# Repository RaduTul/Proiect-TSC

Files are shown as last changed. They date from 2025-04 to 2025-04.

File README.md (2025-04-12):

# Proiect-TSC 
Tulumb Radu Cristian 332CB
e-book reader

Procesul de dezvoltare
In prima parte a proiectului cand am realizat schematicul m-am folosit de descrierea pieselor din pdf-ul de pe OCW pentru a denumi, aranja si a da valori componentelor. Am schimbat de fiecare data layerul cand ba puneam nets ba symbols ba lines. M-am folosit de toolurile necesare pentru a schimba numele si valorile pieselor apoi am dat switch in PCB.
In PCB am tinut cont de masuratorile de pe OCW si de pozitia componentelor. Ca sa ma asigur ca dimensiunea placutei este corecta am modificat gridul PCB-ului in 1 mm cu 1 mm pentru a determina daca este dimensiunea corecta. Rutarea a fost mai complicata, dar am reusit sa o fac pe layerul de top si bottom. Mai aveam doua erori hole carora le-am dat approve. Pentru a continua am dat switch in PCB3D.
Am cautat piesele individual folosind design manager si sintaxa (ObjectType = Device) AND (Name = "piesa respectiva") pentru a cauta piesa pentru care urma sa fac un model 3D. Modelele 3D au fost luate de pe SnapMagic, Mouser, SnapEDA si componentsearchengine unde am gasit modelele 3D pentru fiecare piesa in parte. Am creat un fisier special cu toate modelele 3D necesare, le-am rotit si ajustat pentru a se incadra in linia punctata verde si intre cele doua puncte verzi si i-am dat replace package apoi am salvat, am dat in PCB update apoi cand dadeam switch to PCB3D imi punea piesa pe placuta. Pentru TP-uri am desenat un cerc.
Pentru generarea fisierelor Gerber am folosit optiunea de Fabrication Outputs din meniul MANUFACTURE din Fusion 360. Am selectat toate straturile necesare (Top Copper, Bottom Copper, Top Mask, Bottom Mask, Top Paste, Bottom Paste, Top Silkscreen, Bottom Silkscreen si Edge Cuts) si am generat fisierele in formatul cerut.
Am generat fisierul BOM (Bill of Materials) utilizand functionalitatea din meniul MANAGE, selectand toate componentele folosite in proiect si exportand in formatul CSV, apoi l-am salvat in directorul Manufacturing.
Fisierul Pick and Place (CPL) a fost generat din meniul MANUFACTURE, sectiunea Assembly, selectand optiunile pentru coordonatele componentelor si formatand corespunzator pentru productie.
Probleme la implementare
Aprobarea erorilor
La rutarea PCB-ului a fost nevoie sa aprob 2 erori de "hole" cauzate de componentele SMD.
Lipsa model 3D
Pentru TP-uri nu am gasit un model 3D, asa ca am facut un cerc pe care l-am ridicat putin.

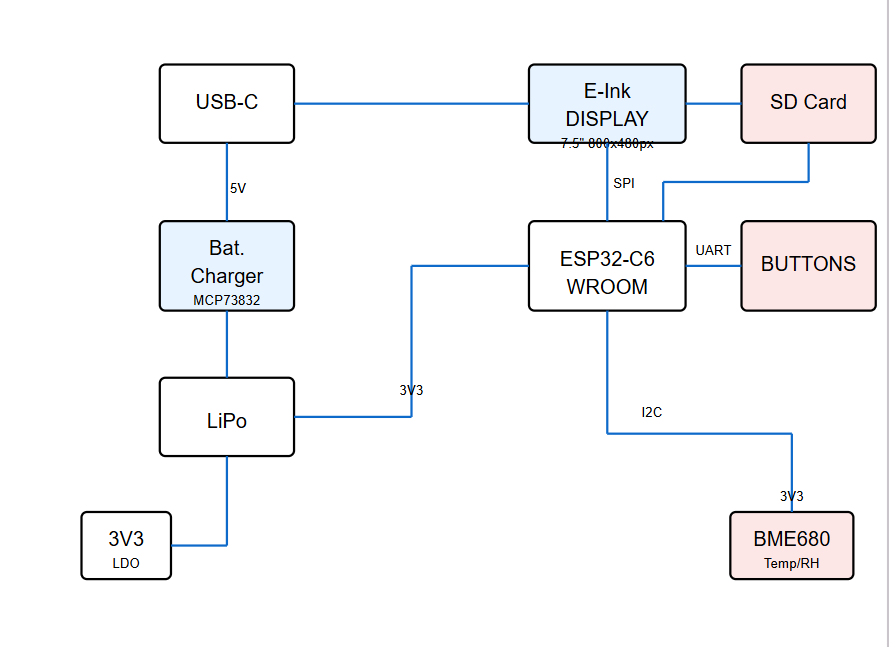
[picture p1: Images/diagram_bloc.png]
Diagrama Bloc OpenBook


[(BOM)](Manufacturing/BOM_proiect2025%20v19.csv)

## Functionalitatile Hardware
Acest e-book reader foloseste un microcontroller ESP32-C6 WROOM care controleaza un display e-ink de 7.5" cu rezolutie 800x480px. Dispozitivul include urmatoarele componente principale:
Componente Hardware Utilizate

ESP32-C6: Microcontroller principal pentru procesarea datelor si conectivitate.
E-Paper Display 7.5": Display cu consum redus de energie, conectat prin SPI.
Conectori pentru SD Card: Permite stocarea suplimentara a cartilor electronice.
Memorie NOR Flash W25Q512: Stocare suplimentara pentru fisiere tip e-book.
Baterie Li-Po: Sursa principala de alimentare a dispozitivului.
Conector USB-C: Permite incarcarea si transferul de date.
Modul RTC DS3231SN: Functionalitate de ceas in timp real.
Senzor BME680: Monitorizeaza temperatura si umiditate prin interfata I2C.
MAX17048G: Circuit de management pentru baterie.

## Interfete Principale

SPI: Utilizata pentru E-Paper display si memoria Flash.
I2C: Conecteaza senzorul BME680 si modulul RTC.
GPIO: Utilizati pentru butoane si alte componente periferice.

## Pini Utilizati - ESP32-C6

GPIO6 (IO6): SCK pentru interfata SPI (inlocuieste GPIO3/GPIO18/GPIO19 din listarea initiala).
GPIO2 (IO2): MISO pentru interfata SPI.
GPIO7 (IO7): MOSI pentru interfata SPI (inlocuieste GPIO1 din listarea initiala).
GPIO11 (IO11): Chip Select pentru memoria Flash (inlocuieste GPIO5 din listarea initiala).
GPIO3 (IO3): Reset pentru E-Paper (inlocuieste GPIO4 din listarea initiala).
GPIO4 (IO4): Chip Select pentru cardul SD (inlocuieste GPIO10 din listarea initiala).
GPIO22 (IO22): SCL pentru interfata I2C.
GPIO21 (IO21): SDA pentru interfata I2C.
GPIO16 (IO16): TX pentru comunicatie seriala.
GPIO17 (IO17): RX pentru comunicatie seriala.
GPIO20 (IO20): Conectat la butonul BOOT.
GPIO21 (IO21): Conectat la butonul RESET (posibil duplicat cu SDA, necesita verificare in schematic).
GPIO22 (IO22): Conectat la butonul CHANGE (posibil duplicat cu SCL, necesita verificare in schematic).

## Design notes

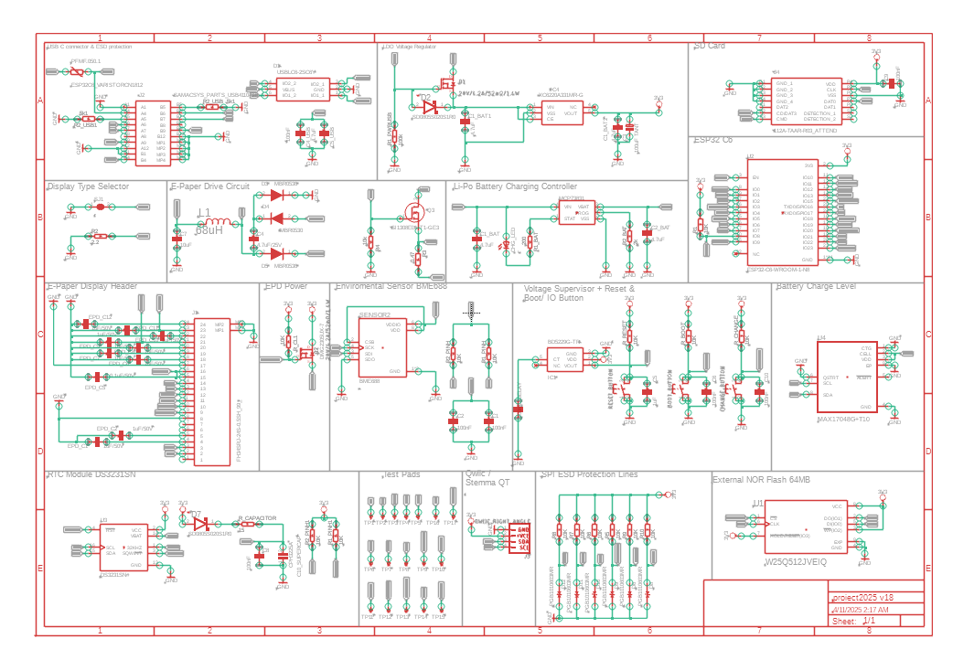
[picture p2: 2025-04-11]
Images/schematicdupareview.PNG

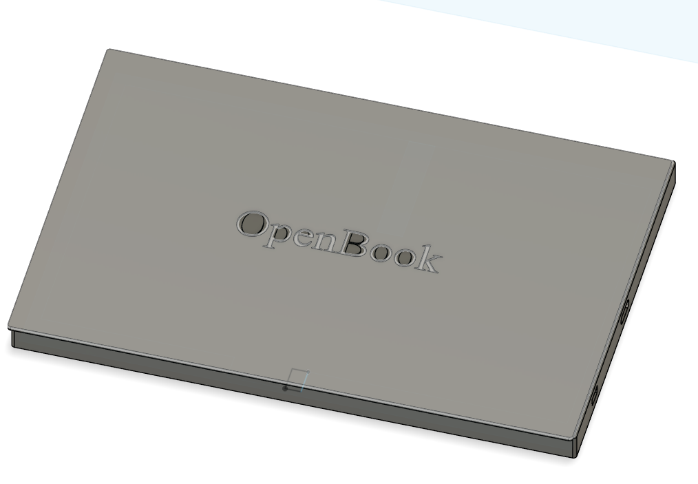
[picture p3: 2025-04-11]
Images/carcasainchisa.PNG

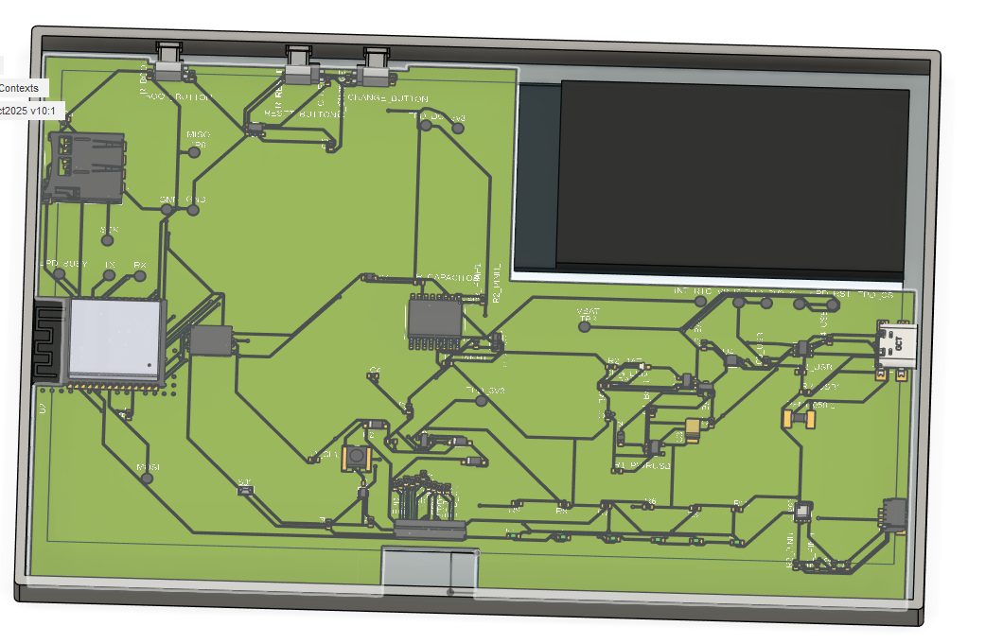
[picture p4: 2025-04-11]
Images/3docbdupareview.PNG

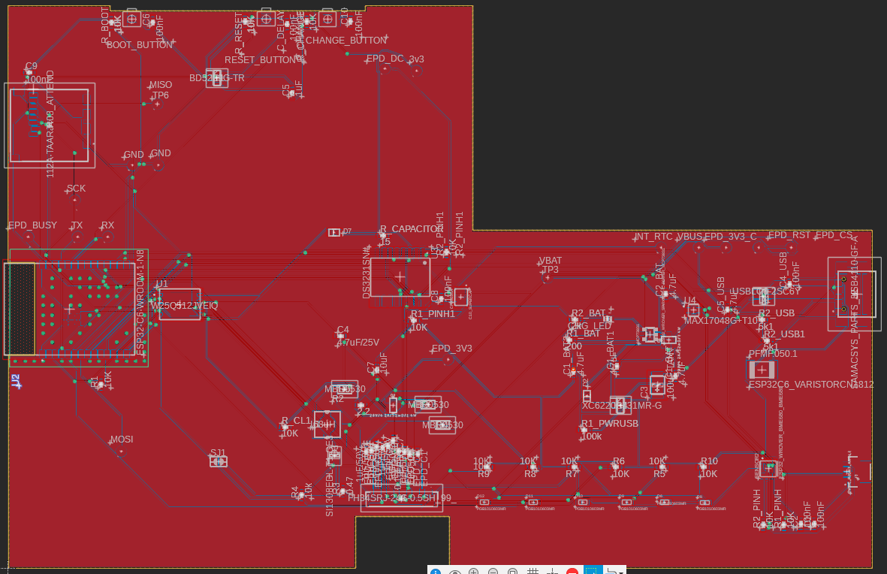
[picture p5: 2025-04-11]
Images/pcbafterreview.PNG

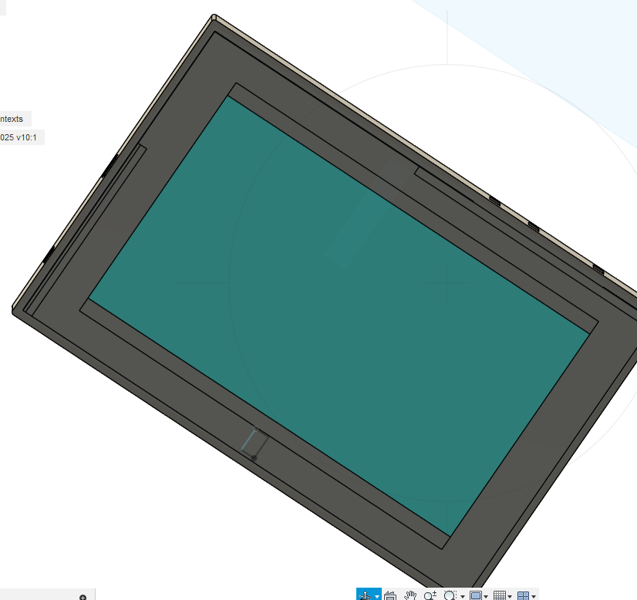
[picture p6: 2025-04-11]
Images/carcasa displau.PNG

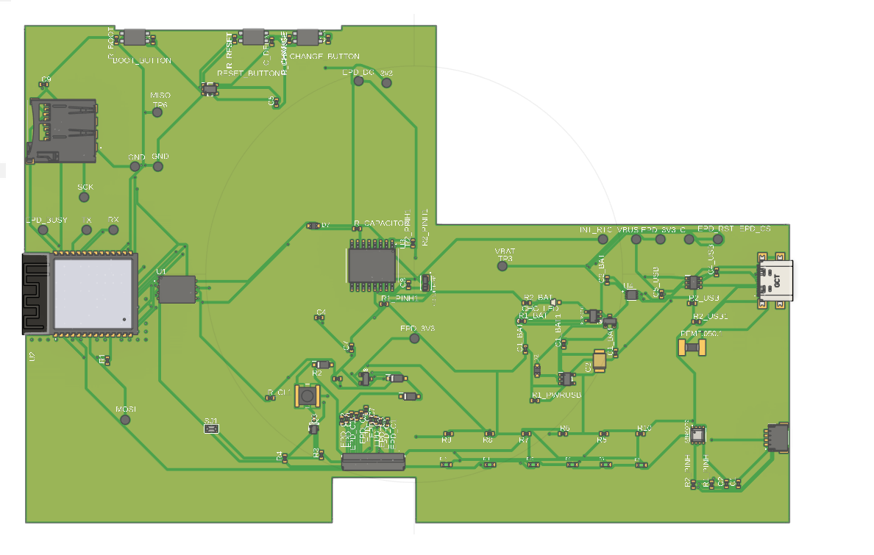
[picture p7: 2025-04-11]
Images/pcb3ddupareview.PNG

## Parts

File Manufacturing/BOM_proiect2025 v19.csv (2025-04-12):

Qty | Value | Device | Package | Parts | Description | ARROW_PART_NUMBER | ARROW_PRICE-STOCK | AVAILABILITY | CENTROID_NOT_SPECIFIED | CHECK_PRICES | COPYRIGHT | DATASHEET | DESCRIPTION | DIGIKEY_DESCRIPTION | DIGIKEY_PART_NUMBER | HEIGHT | LEAD_FREE | MANUFACTURER_NAME | MANUFACTURER_PART_NUMBER | MF | MFR_NAME | MOUSER_PART_NUMBER | MOUSER_PRICE-STOCK | MOUSER_TESTING_PART_NUMBER | MOUSER_TESTING_PRICE-STOCK | MP | MPN | PACKAGE | POPULARITY | PREFIX | PRICE | PROD_ID | PURCHASE-URL | ROHS | SNAPEDA_LINK | SPICEMODEL | SPICEPREFIX | TEMPERATURE_RANGE_HIGH | TEMPERATURE_RANGE_LOW | TP_SIGNAL_NAME | VALUE
1 |  | ADAFRUIT_LEDCHIP-LED0603 | ADAFRUIT_CHIP-LED0603 | CHG_LED | LED
2 |  | ESP32_WROVER_EAGLE-LTSPICE_RR0402 | ESP32_WROVER_EAGLE-LTSPICE_R0402 | R1, R2 | RESISTOR, European symbol |  |  |  |  |  |  |  |  |  |  |  |  |  |  |  |  |  |  |  |  |  |  |  |  |  |  |  |  |  |  | NONE | R
1 |  | SJ | SJ | SJ1 | SMD solder JUMPER |  |  |  |  |  |  |  |  |  |  |  |  |  |  |  |  |  |  |  |  |  |  |  | 3
1 | 0.1uF/50V | EAGLE-LTSPICE_CC0402 | EAGLE-LTSPICE_C0402 | EPD_C5 | CAPACITOR, European symbol |  |  |  |  |  |  |  |  |  |  |  |  |  |  |  |  |  |  |  |  |  |  |  |  |  |  |  |  |  |  | NONE | C
1 | 0.47 | ESP32_WROVER_EAGLE-LTSPICE_RR0402 | ESP32_WROVER_EAGLE-LTSPICE_R0402 | R3 | RESISTOR, European symbol |  |  |  |  |  |  |  |  |  |  |  |  |  |  |  |  |  |  |  |  |  |  |  |  |  |  |  |  |  |  | NONE | R
1 | 100k | ESP32_WROVER_EAGLE-LTSPICE_RR0402 | ESP32_WROVER_EAGLE-LTSPICE_R0402 | R1_PWRUSB | RESISTOR, European symbol |  |  |  |  |  |  |  |  |  |  |  |  |  |  |  |  |  |  |  |  |  |  |  |  |  |  |  |  |  |  | NONE | R
8 | 100nF | EAGLE-LTSPICE_CC0402 | EAGLE-LTSPICE_C0402 | C1, C2, C4_USB, C6, C8, C9, C10, C_DELAY | CAPACITOR, European symbol |  |  |  |  |  |  |  |  |  |  |  |  |  |  |  |  |  |  |  |  |  |  |  |  |  |  |  |  |  |  | NONE | C
1 | 100uF TANT | RCL_CPOL-EUCT3528 | RCL_CT3528 | C3 | POLARIZED CAPACITOR, European symbol |  |  |  |  |  |  |  |  |  |  |  |  |  |  |  |  |  |  |  |  |  |  |  | 0 |  |  |  |  |  |  |  | C
14 | 10K | ESP32_WROVER_EAGLE-LTSPICE_RR0402 | ESP32_WROVER_EAGLE-LTSPICE_R0402 | R1_PINH, R1_PINH1, R2_PINH, R2_PINH1, R5, R6, R7, R8, R9, R10, R_BOOT, R_CHANGE, R_CL1, R_RESET | RESISTOR, European symbol |  |  |  |  |  |  |  |  |  |  |  |  |  |  |  |  |  |  |  |  |  |  |  |  |  |  |  |  |  |  | NONE | R
1 | 10k | ESP32_WROVER_EAGLE-LTSPICE_RR0402 | ESP32_WROVER_EAGLE-LTSPICE_R0402 | R4 | RESISTOR, European symbol |  |  |  |  |  |  |  |  |  |  |  |  |  |  |  |  |  |  |  |  |  |  |  |  |  |  |  |  |  |  | NONE | R
1 | 10uF | EAGLE-LTSPICE_CC0402 | EAGLE-LTSPICE_C0402 | C7 | CAPACITOR, European symbol |  |  |  |  |  |  |  |  |  |  |  |  |  |  |  |  |  |  |  |  |  |  |  |  |  |  |  |  |  |  | NONE | C
1 | 112A-TAAR-R03_ATTEND | 112A-TAAR-R03_ATTEND | 112ATAARR03ATTEND | J4 | Micro SD Card Socket, Push-Push Type, Top Mount, SMT, H=1.83mm, 10u |  |  |  |  |  |  |  | Micro SD Card Socket | Push-Push Type | Top Mount | SMT | H=1.83mm | 10u |  |  | 1.9mm |  | ATTEND | 112A-TAAR-R03 ATTEND
1 | 15 | ESP32_WROVER_EAGLE-LTSPICE_RR0402 | ESP32_WROVER_EAGLE-LTSPICE_R0402 | R_CAPACITOR | RESISTOR, European symbol |  |  |  |  |  |  |  |  |  |  |  |  |  |  |  |  |  |  |  |  |  |  |  |  |  |  |  |  |  |  | NONE | R
1 | 1uF | EAGLE-LTSPICE_CC0402 | EAGLE-LTSPICE_C0402 | C5 | CAPACITOR, European symbol |  |  |  |  |  |  |  |  |  |  |  |  |  |  |  |  |  |  |  |  |  |  |  |  |  |  |  |  |  |  | NONE | C
9 | 1uF/50V | EAGLE-LTSPICE_CC0402 | EAGLE-LTSPICE_C0402 | EPD_C1, EPD_C2, EPD_C6, EPD_C7, EPD_C8, EPD_C9, EPD_C10, EPD_C11, EPD_C12 | CAPACITOR, European symbol |  |  |  |  |  |  |  |  |  |  |  |  |  |  |  |  |  |  |  |  |  |  |  |  |  |  |  |  |  |  | NONE | C
1 | 200 | ESP32_WROVER_EAGLE-LTSPICE_RR0402 | ESP32_WROVER_EAGLE-LTSPICE_R0402 | R1_BAT | RESISTOR, European symbol |  |  |  |  |  |  |  |  |  |  |  |  |  |  |  |  |  |  |  |  |  |  |  |  |  |  |  |  |  |  | NONE | R
2 | 20V/4.2A/52mO/1.4W | ESP32_WROVER_SPARKFUN-DISCRETESEMI_MOSFET_PCH-DMG2305UX-7 | ESP32_WROVER_SPARKFUN-DISCRETESEMI_SOT23-3 | Q1, Q2 | P-channel MOSFETs |  |  |  |  |  |  |  |  |  |  |  |  |  |  |  |  |  |  |  |  |  |  |  |  |  |  | TRAN-14388 |  |  |  |  |  |  |  |  | 20V/4.2A/52mO/1.4W
1 | 2k | ESP32_WROVER_EAGLE-LTSPICE_RR0402 | ESP32_WROVER_EAGLE-LTSPICE_R0402 | R2_BAT | RESISTOR, European symbol |  |  |  |  |  |  |  |  |  |  |  |  |  |  |  |  |  |  |  |  |  |  |  |  |  |  |  |  |  |  | NONE | R
5 | 4.7uF | EAGLE-LTSPICE_CC0402 | EAGLE-LTSPICE_C0402 | C1_BAT, C1_BAT1, C1_BAT2, C2_BAT, C5_USB | CAPACITOR, European symbol |  |  |  |  |  |  |  |  |  |  |  |  |  |  |  |  |  |  |  |  |  |  |  |  |  |  |  |  |  |  | NONE | C
1 | 4.7uF/25V | EAGLE-LTSPICE_CC0402 | EAGLE-LTSPICE_C0402 | C4 | CAPACITOR, European symbol |  |  |  |  |  |  |  |  |  |  |  |  |  |  |  |  |  |  |  |  |  |  |  |  |  |  |  |  |  |  | NONE | C
2 | 5k1 | ESP32_WROVER_EAGLE-LTSPICE_RR0402 | ESP32_WROVER_EAGLE-LTSPICE_R0402 | R2_USB, R2_USB1 | RESISTOR, European symbol |  |  |  |  |  |  |  |  |  |  |  |  |  |  |  |  |  |  |  |  |  |  |  |  |  |  |  |  |  |  | NONE | R
1 | 68uH | 744043680IND_4828-WE-TPC_WRE | IND_4828-WE-TPC_WRE | L1 |  |  |  |  |  |  | Copyright (C) 2024 Ultra Librarian. All rights reserved. |  |  |  |  |  |  |  | 744043680 |  | Wurth Electronics
1 | BD5229G-TR | BD5229G-TR | SOT95P280X125-5N | IC1 | Voltage Detector with Adjustable Delay Time: CMOS processes are utilized to develop high precision, low current consumption CMOS reset ICs that allow arbitrary setting of the delay time. The extensive lineup includes both Nch Open Drain and CMOS output types in a wide range of detection voltages (from 2.3V to 6.0V, in 0.1V steps), enabling selection of the ideal solution based on customer requirements. In addition, the entire series is of course both lead-free and RoHS-compliant. |  |  |  |  |  |  |  | Voltage Detector with Adjustable Delay Time: CMOS processes are utilized to develop high precision | low current consumption CMOS reset ICs that allow arbitrary setting of the delay time. The extensive lineup includes both Nch Open Drain and CMOS output types in a wide range of detection voltages (from 2.3V to 6.0V | in 0.1V steps) | enabling selection of the ideal solution based on customer requirements. In addition | the entire series is of course both lead-free and RoHS-compliant. |  |  | 1.25mm |  | ROHM Semiconductor | BD5229G-TR |  |  | 755-BD5229G-TR | https://www.mouser.co.uk/ProductDetail/ROHM-Semiconductor/BD5229G-TR?qs=4kLU8WoGk0vvnhrrYwdszw%3D%3D
3 | BUTTON_CUSYOMV1 | BUTTON_CUSYOMV1 | MYBUTTON | BOOT_BUTTON, CHANGE_BUTTON, RESET_BUTTON |  |  |  |  |  |  |  |  |  |  |  |  |  |  |  |  |  |  |  |  |  |  | https://www.mouser.co.il/ProductDetail/SparkFun/COM-09190?qs=WyAARYrbSnYmfgv9mXV0oQ%3D%3D
1 | CPH3225A | CPH3225A | CAPCP3225X100N | C10_SUPERCAP | Cap 0.011F 3.3V 1210 Flat Check availability |  |  | Not in stock |  | https://www.snapeda.com/parts/CPH3225A/Seiko+Instruments/view-part/?ref=eda |  |  | 11 mF (EDLC) Supercapacitor 3.3 V 1210 (3225 Metric) - - |  |  |  |  |  |  | Seiko Instruments |  |  |  |  |  | CPH3225A |  | 1210 Seiko |  |  | None |  | https://www.snapeda.com/api/url_track_click_mouser/?unipart_id=562593&manufacturer=Seiko Instruments&part_name=CPH3225A&search_term=None |  | https://www.snapeda.com/parts/CPH3225A/Seiko+Instruments/view-part/?ref=snap
1 | DS3231SN# | DS3231SN# | SOIC127P1032X265-16N | U3 | Real Time Clock Serial 16-Pin SOIC W T/R Check availability |  |  | In Stock |  | https://www.snapeda.com/parts/DS3231SN%23/Analog+Devices/view-part/?ref=eda |  |  | Extremely Accurate I²C-Integrated RTC/TCXO/Crystal |  |  |  |  |  |  | Analog Devices |  |  |  |  |  | DS3231SN# |  | SOIC-16 Maxim |  |  | None |  | https://www.snapeda.com/api/url_track_click_mouser/?unipart_id=99048&manufacturer=Analog Devices&part_name=DS3231SN#&search_term=None |  | https://www.snapeda.com/parts/DS3231SN%23/Analog+Devices/view-part/?ref=snap
1 | ESP32-C6-WROOM-1-N8 | ESP32-C6-WROOM-1-N8 | XCVR_ESP32-C6-WROOM-1-N8 | U2 | Check availability |  |  | In Stock |  | https://www.snapeda.com/parts/ESP32-C6-WROOM-1-N8/Espressif+Systems/view-part/?ref=eda |  |  | Multiprotocol Modules ESP32-C6 module | Wi-Fi 6 in 2.4 GHz band | Bluetooth 5 | Zigbee 3.0 and Thread. ESP34-WROOM Compatible - ENGINEERING SAMPLE |  |  |  |  |  |  | Espressif Systems |  |  |  |  |  | ESP32-C6-WROOM-1-N8 |  | None |  |  | None |  |  |  | https://www.snapeda.com/parts/ESP32-C6-WROOM-1-N8/Espressif+Systems/view-part/?ref=snap
1 | ESP32C6_VARISTORCN1812 | ESP32C6_VARISTORCN1812 | ESP32C6_VARISTOR_CT/CN1812 | PFMF.050.1 | VARISTOR |  |  |  |  |  |  |  |  |  |  |  |  |  |  |  |  |  |  |  |  |  | https://eu.mouser.com/ProductDetail/Espressif-Systems/ESP32-C6?qs=Imq1NPwxi75noDtUpuVuWw%3D%3D |  | 0
2 | ESP32_WROVER_AVX---SD0805S020S1R0_AVX_SD0805S020S1R0_0_0AVX_SD0805S020S1R0_0_0 | ESP32_WROVER_AVX---SD0805S020S1R0_AVX_SD0805S020S1R0_0_0AVX_SD0805S020S1R0_0_0 | ESP32_WROVER_AVX---SD0805S020S1R0_AVX_SD0805S020S1R0_0 | D2, D7 | Schottky Barrier Rectifier Diode |  |  |  | No |  |  | http://datasheets.avx.com/schottky.pdf |  | DIODE SCHOTTKY 20V 1A 0805 | 478-7800-1-ND |  | yes |  |  | AVX |  | 581-SD0805S020S1R0 |  |  |  |  | https://eu.mouser.com/ProductDetail/Espressif-Systems/ESP32-WROVER-IE-N4R8?qs=Li%252BoUPsLEntmub0i0FT64w%3D%3D | 0805 (2012 metric) |  | D |  |  |  | yes |  |  |  | +125°C | -55°C
1 | ESP32_WROVER_BME680_BME680 | ESP32_WROVER_BME680_BME680 | ESP32_WROVER_BME680_PSON80P300X300X100-8N | SENSOR2 | Integrated Environmental Unit |  |  | Unavailable |  |  |  |  | Integrated Environmental Unit |  |  |  |  |  |  | Bosch Sensortec |  |  |  |  |  | BME680 | https://ro.mouser.com/ProductDetail/Bosch-Sensortec/BME680?qs=v271MhAjFHjo0yA%2FC4OnDQ%3D%3D | LGA-8 Bosch Tools |  |  | None
1 | ESP32_WROVER_SPARKFUN-IC-POWER_MCP73831 | ESP32_WROVER_SPARKFUN-IC-POWER_MCP73831 | ESP32_WROVER_SPARKFUN-IC-POWER_SOT23-5 | MCP73831 | MCP73831T Li-Ion, Li-Pol Controller |  |  |  |  |  |  |  |  |  |  |  |  |  |  |  |  |  |  |  |  |  | https://eu.mouser.com/ProductDetail/Microchip-Technology/MCP73831T-2ACI-OT?qs=yUQqVecv4qvbBQBGbHx0Mw%3D%3D |  |  |  |  | IC-09995
1 | FH34SRJ-24S-0.5SH_99_ | FH34SRJ-24S-0.5SH_99_ | FH34SRJ24S05SH99 | J1 | (0.50mm) Surface Mount, Right Angle |  |  |  |  |  |  |  | 24 Position FFC | FPC Connector Contacts | (0.50mm) Surface Mount | Right Angle |  |  | 1.1mm |  | Hirose | FH34SRJ-24S-0.5SH(99) |  |  | 798-FH34SRJ24S05SH99 | https://www.mouser.co.uk/ProductDetail/Hirose-Connector/FH34SRJ-24S-0.5SH99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
1 | MAX17048G+T10 | MAX17048G+T10 | SON50P200X200X80-9N | U4 | Check availability |  |  | In Stock |  | https://www.snapeda.com/parts/MAX17048G+T10/Analog+Devices/view-part/?ref=eda |  |  | 3µA 1-Cell/2-Cell Fuel Gauge with ModelGauge |  |  |  |  |  |  | Analog Devices |  |  |  |  |  | MAX17048G+T10 |  | TDFN-8 Maxim |  |  | None |  | https://www.snapeda.com/api/url_track_click_mouser/?unipart_id=329239&manufacturer=Analog Devices&part_name=MAX17048G+T10&search_term=None |  | https://www.snapeda.com/parts/MAX17048G+T10/Analog+Devices/view-part/?ref=snap
3 | MBR0530 | MBR0530 | SOD3716X135N | D3, D4, D5 | ON SEMICONDUCTOR - MBR0530 - DIODE, SCHOTTKY, 0.5A, 30V, SOD-123 |  |  | In Stock |  | https://www.snapeda.com/parts/MBR0530/Onsemi/view-part/?ref=eda |  |  | Diode Schottky 30 V 500mA Surface Mount SOD-123 |  |  |  |  |  |  | ON Semiconductor |  |  |  |  |  | MBR0530 |  | SOD-123-2 ON Semiconductor |  |  | None |  | https://www.snapeda.com/api/url_track_click_mouser/?unipart_id=179458&manufacturer=ON Semiconductor&part_name=MBR0530&search_term=None |  | https://www.snapeda.com/parts/MBR0530/Onsemi/view-part/?ref=snap
6 | PGB1010603MR | PGB1010603MR | DIOC1608X36N | D6, D8, D9, D10, D11, D12 | Check availability |  |  | In Stock |  | https://www.snapeda.com/parts/PGB1010603MR/Littelfuse/view-part/?ref=eda |  |  | 150V (Typ) Clamp - Ipp Tvs Diode Surface Mount 0603 (1608 Metric) |  |  |  |  |  |  | Littelfuse Inc. |  |  |  |  |  | PGB1010603MR |  | 0603 Littelfuse Inc. |  |  | None |  | https://www.snapeda.com/api/url_track_click_mouser/?unipart_id=5659453&manufacturer=Littelfuse Inc.&part_name=PGB1010603MR&search_term=None |  | https://www.snapeda.com/parts/PGB1010603MR/Littelfuse/view-part/?ref=snap
1 | QWIIC_RIGHT_ANGLE | QWIIC_CONNECTORJS-1MM | JST04_1MM_RA | J3 | SparkFun I2C Standard Qwiic Connector |  |  |  |  |  |  |  |  |  |  |  |  |  |  |  |  |  |  |  |  |  | https://ro.mouser.com/new/sparkfun/sparkfun-qwiic-connect-system/ |  |  |  |  | CONN-13694 |  |  |  |  |  |  |  |  | QWIIC_RIGHT_ANGLE
1 | SAMACSYS_PARTS_USB4110-GF-A | SAMACSYS_PARTS_USB4110-GF-A | SAMACSYS_PARTS_USB4110GFA | J2 | CONN USB 2.0 TYPE-C R/A SMT |  |  |  |  |  |  |  | CONN USB 2.0 TYPE-C R/A SMT |  |  | 3.26mm |  | GCT (GLOBAL CONNECTOR TECHNOLOGY) | USB4110-GF-A |  |  | 640-USB4110-GF-A | https://www.mouser.co.uk/ProductDetail/GCT/USB4110-GF-A?qs=KUoIvG%2F9IlYiZvIXQjyJeA%3D%3D
1 | SI1308EDL-T1-GE3 | SI1308EDL-T1-GE3 | SOT65P210X110-3N | Q3 | MOSFET N-Ch 30V 1.5A TrenchFET SC70 Vishay Si1308EDL-T1-GE3 N-channel MOSFET Transistor, 1.5 A, 30 V, 3-Pin SC-70 |  |  | In Stock |  | https://www.snapeda.com/parts/SI1308EDL-T1-GE3/Vishay+Siliconix/view-part/?ref=eda |  |  | Si1308EDL-T1-GE3 N-channel MOSFET Transistor | 1.5 A | 30 V | 3-Pin SC-70 | Siliconix / Vishay SI1308EDL-T1-GE3 |  |  |  |  |  |  | Vishay Siliconix |  |  |  |  |  | SI1308EDL-T1-GE3 |  | SOT-323 Vishay Semiconductor |  |  | None |  | https://www.snapeda.com/api/url_track_click_mouser/?unipart_id=274603&manufacturer=Vishay Siliconix&part_name=SI1308EDL-T1-GE3&search_term=None |  | https://www.snapeda.com/parts/SI1308EDL-T1-GE3/Vishay+Siliconix/view-part/?ref=snap
17 | TPTP20R | TPTP20R | TP20R | TP1, TP2, TP3, TP4, TP5, TP6, TP7, TP8, TP9, TP10, TP11, TP12, TP13, TP14, TP15, TP16, TP17 | Test pad |  |  |  |  |  |  |  |  |  |  |  |  |  |  |  |  |  |  |  |  |  |  |  | 2
1 | USBLC6-2SC6Y | USBLC6-2SC6Y | SOT95P280X145-6N | D1 | Low Cap. ESD Protection Auto SOT-23-6 STMicroelectronics USBLC6-2SC6Y, Dual Uni-Directional TVS Diode Array, 6-Pin SOT-23 |  |  | In Stock |  | https://www.snapeda.com/parts/USBLC6-2SC6Y/STMicroelectronics/view-part/?ref=eda |  |  | 17V Clamp 5A (8/20µs) Ipp Tvs Diode Surface Mount SOT-23-6 |  |  |  |  |  |  | STMicroelectronics |  |  |  |  |  | USBLC6-2SC6Y |  | SOT-23-6 STMicroelectronics |  |  | None |  |  |  | https://www.snapeda.com/parts/USBLC6-2SC6Y/STMicroelectronics/view-part/?ref=snap
1 | W25Q512JVEIQ | W25Q512JVEIQ | SON127P600X800X80-9N | U1 | Check availability |  |  | In Stock |  | https://www.snapeda.com/parts/W25Q512JVEIQ/Winbond+Electronics/view-part/?ref=eda |  |  | FLASH - NOR Memory IC 512Mb (64M x 8) SPI - Quad I/O 133 MHz 8-WSON (8x6) |  |  |  |  |  |  | Winbond Electronics |  |  |  |  |  | W25Q512JVEIQ |  | Package |  |  | None |  |  |  | https://www.snapeda.com/parts/W25Q512JVEIQ/Winbond+Electronics/view-part/?ref=snap
1 | XC6220A331MR-G | XC6220A331MR-G | SOT95P280X120-5N | IC4 | LDO Voltage Regulators |  |  |  |  |  |  |  | LDO Voltage Regulators |  |  | 1.2mm |  | Torex | XC6220A331MR-G |  |  | 865-XC6220A331MR-G | https://www.mouser.co.uk/ProductDetail/Torex-Semiconductor/XC6220A331MR-G?qs=AsjdqWjXhJ8ZSWznL1J0gg%3D%3D

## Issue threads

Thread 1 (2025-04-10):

Review: Schematic

george-cosma, 2025-04-10:
# Review: Schematic

În mare e foarte bine. Sunt cateva probleme cu denumiri lipsa sau misaligned, dar alea pot fi din modul in care fusion 360 a dat import, si nu au un impact mare asupra rezultatului final. Sunt si cateva valori lipsa la doua rezistenta.

### ERC
- Cateva warning ce pot rezolvate cum ai mentionat si la review-ul meu. Valoare lipsa  la R2 si R1 par mai serioase totusi. Le-am discutat si mai jos.

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

### LDO Voltage Regulator
- Denumiri de componente ce lipsesc sau sunt departe de componenta (Stanga proiect, Dreapta OCW)
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

### Li-Po Battery Charging Controller
- Firul se suprapune parțial cu label-ul VBUS
- Numele de componenta poate fi sters (mai ales ca se surparune cu foarte multe
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

### E-Paper Driver Circuit
- Fir șui ce se conectează la label-ul de SRC
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

### Display Type SElector
- Resistorul denumit gresit (R1 -> R2) și lipsa valoare
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

### EPD Power
- Denumire tranzistor lipsa
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

### Environmental Sensor BME 688
- Denumirea senzorului poate fi prescurtata
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

### Voltage supervizor
- Putin overlap la label-uri
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

### SPI ESD Protection Lines
- D8 si D6 sunt flipped (cred ca le poti redenumi doar ca sa nu trebuiasca sa modifici apoi si board-ul)
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

### RTC Module
- Denumire lipsa la dioda
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

### ESP32 C6
- Rezistenta are lipsa valoare, si ar trebui numita R1
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

RaduTul, 2025-04-10:
Mersi de review! Sa nu uiti sa pui si label! Am inteles ca e important

RaduTul, 2025-04-10:
Super review! Schematic done!

Closed 2025-04-10.

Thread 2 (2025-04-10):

Review: PCB

george-cosma, 2025-04-10:
# Review: PCB

Aici din păcate sunt mai multe probleme. S-ar putea ca câteva să fie de la modul în care s-a făcut procesul de import/export să se piardă/schimbe chestii de la tine la mine. Îmi place modelul pe care l-ai găsit pentru SD Card Holder și îmi place plasarea componentelor.

### Rutele de putere sunt rutate cu 0.127 mm, nu cu 0.3 mm

Am observat ca ai facut net classes (ceea ce e smart), dar net-urile de power au ramas in clasa default, si nu au fost mutate in clasa power.

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

### Via Stiching
Via stiching lipsa, le poti crea cu Route > Via Stiching

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

### Condensator pe bottom
Trebuia sa ai toate componentele pe top, dar ai un condensator pe bottom. Am observat asta de la faptul ca fusion ti-a creat un fisier Pick and Place pentru bottom, cand el nu ar trebui sa faca asta daca nu ai nimic pe bottom.

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

### Via-uri destul de multe la traseele de putere

Ai cam 20 de via-uri pt putere, ceea ce e destul de mult. Dacă crezi că poți să mai scoți din ele te-aș încuraja să o faci.

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

### Rutele de ground pot fi eliminate

Fiindcă ai ground plane și pe top și pe bottom, nu ai nevoie să tragi fir de la fiecare componentă la fiecare altă componentă. Majoritatea s-ar putea să le poti scoate, și dacă se plânge ca sunt câteva ground-uri neconectate, poți plasa un via intre ground plane-uri și șansele sunt ca o să meargă. Eventual, câteva s-ar putea să fie necesare, but not always. Via Stiching ajută cu asta.

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

### Silkscreen issues
Sunt nume de componente ce ies de pe placă șu test point-urile nu sunt denumite după semnalul ce îl poartă (trebuie să creezi un text pe layer-ul de silkscreen top, si să dai hide la numele te TP ca altfel daca dai rename le dă rename și pe schematic).

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

### Board-ul trebuie decupat sub antena

Sub partea hashurata (cu puncte) nu trebuie sa se afle PCB -- adica trebuie decupat in regiunea aia.

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

### Model baterie și display lipsa?
În OpenBook Enclosure v1 pare sa nu aiba in el bateria și display-ul deși pare că le-ai făcut din moment ce ai poze cu ele în folderul images. A dat fuck up la mine fusion cand a dat import?

### Cateva modele 3d wonky

Cateva din modelele 3d sunt putin gresit pozitionate, nu e o problema mare, dar am zis sa iti mentionez ca sa stii de ele.
- Senzorul BME și mufa USB C Leviteaza

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

- PFMF ar putea fi scalat putin mai mare ca sa faca contact cu pad-urile

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

- La fel si bobina

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

- Q3 nu face contact cu pad-urle de loc (trebuie rotit 90 de grade)

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

- Nu imi dau seama foarte bine din poza, dar mi se pare ca supercap pare a fi rotit in placa, si se suprapune cu place destul de mult. IDK double check sa nu fie ceva problema de import

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

RaduTul, 2025-04-10:
Super am rezolvat si pe partea de pcb si partea de pcb3d. Ai descris superb fiecare problema in parte si iti multumesc pentru asta.Nu stiu daca a dat fuckup, dar eu am displayul si bateria facute.

Closed 2025-04-10.

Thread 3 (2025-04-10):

Review: README

george-cosma, 2025-04-10:
README-ul în mare e okay. Am doar două sau trei observații de făcut:
- Senzorul BME680 cred că încorporează și ceilalți doi senzori pe care i-au pus tu în diagrama block. Cum e pus acum dă impresia că sunt mai multe chip-uri, cand e doar un singur chip - cel de BME alimentat de la 3v3
- Avem doar alimentare de 3v3 (schema block)
- Paper display-ul e de 7.5'' inch 800 px X 480 px
- Pinii par putin jumbled up -- eu m-am luat după diagrama din schematic direct
  - GPIO18, GPIO19: SCK si MISO pentru interfata SPI.  -> IO6, IO2
  - GPIO5: Chip Select pentru memoria Flash. -> IO11
  - GPIO4: Reset pentru E-Paper. -> IO3
  - GPIO22: SCL pentru interfata I2C. -> OK
  - GPIO21: SDA pentru interfata I2C. -> OK
  - GPIO16: TX pentru comunicatie seriala. -> OK
  - GPIO17: RX pentru comunicatie seriala. -> OK
  - GPIO20, GPIO21, GPIO22: Conectati la butoanele de control. -> Not sure?
  - GPIO10: Chip Select pentru cardul SD. -> IO4
  - GPIO1: MOSI pentru interfata SPI. -> IO7
  - GPIO2: MISO pentru dispozitive SPI. -> Duplicate, dar OK
  - GPIO3: SCK pentru comunicatie SPI. -> Duplicate, IO6
- La Bill Of Materials din README, trebuie să pui și link de achiziție și link la datasheet. Majoritatea componentelor le găsești direct pe mouser, care are direct și datasheet.

george-cosma, 2025-04-11:
@RaduTul  Am scris acuma aici, GJ so far, și GG la cat de repede te-ai mișcat să rezolvi celalte 2 issue-uri!

RaduTul, 2025-04-12:
Thank you <3

RaduTul, 2025-04-12:
Done. It has been a pleasure working with you! Spor in continuare! <3

george-cosma, 2025-04-12:
La fel! Spor

Closed 2025-04-12.

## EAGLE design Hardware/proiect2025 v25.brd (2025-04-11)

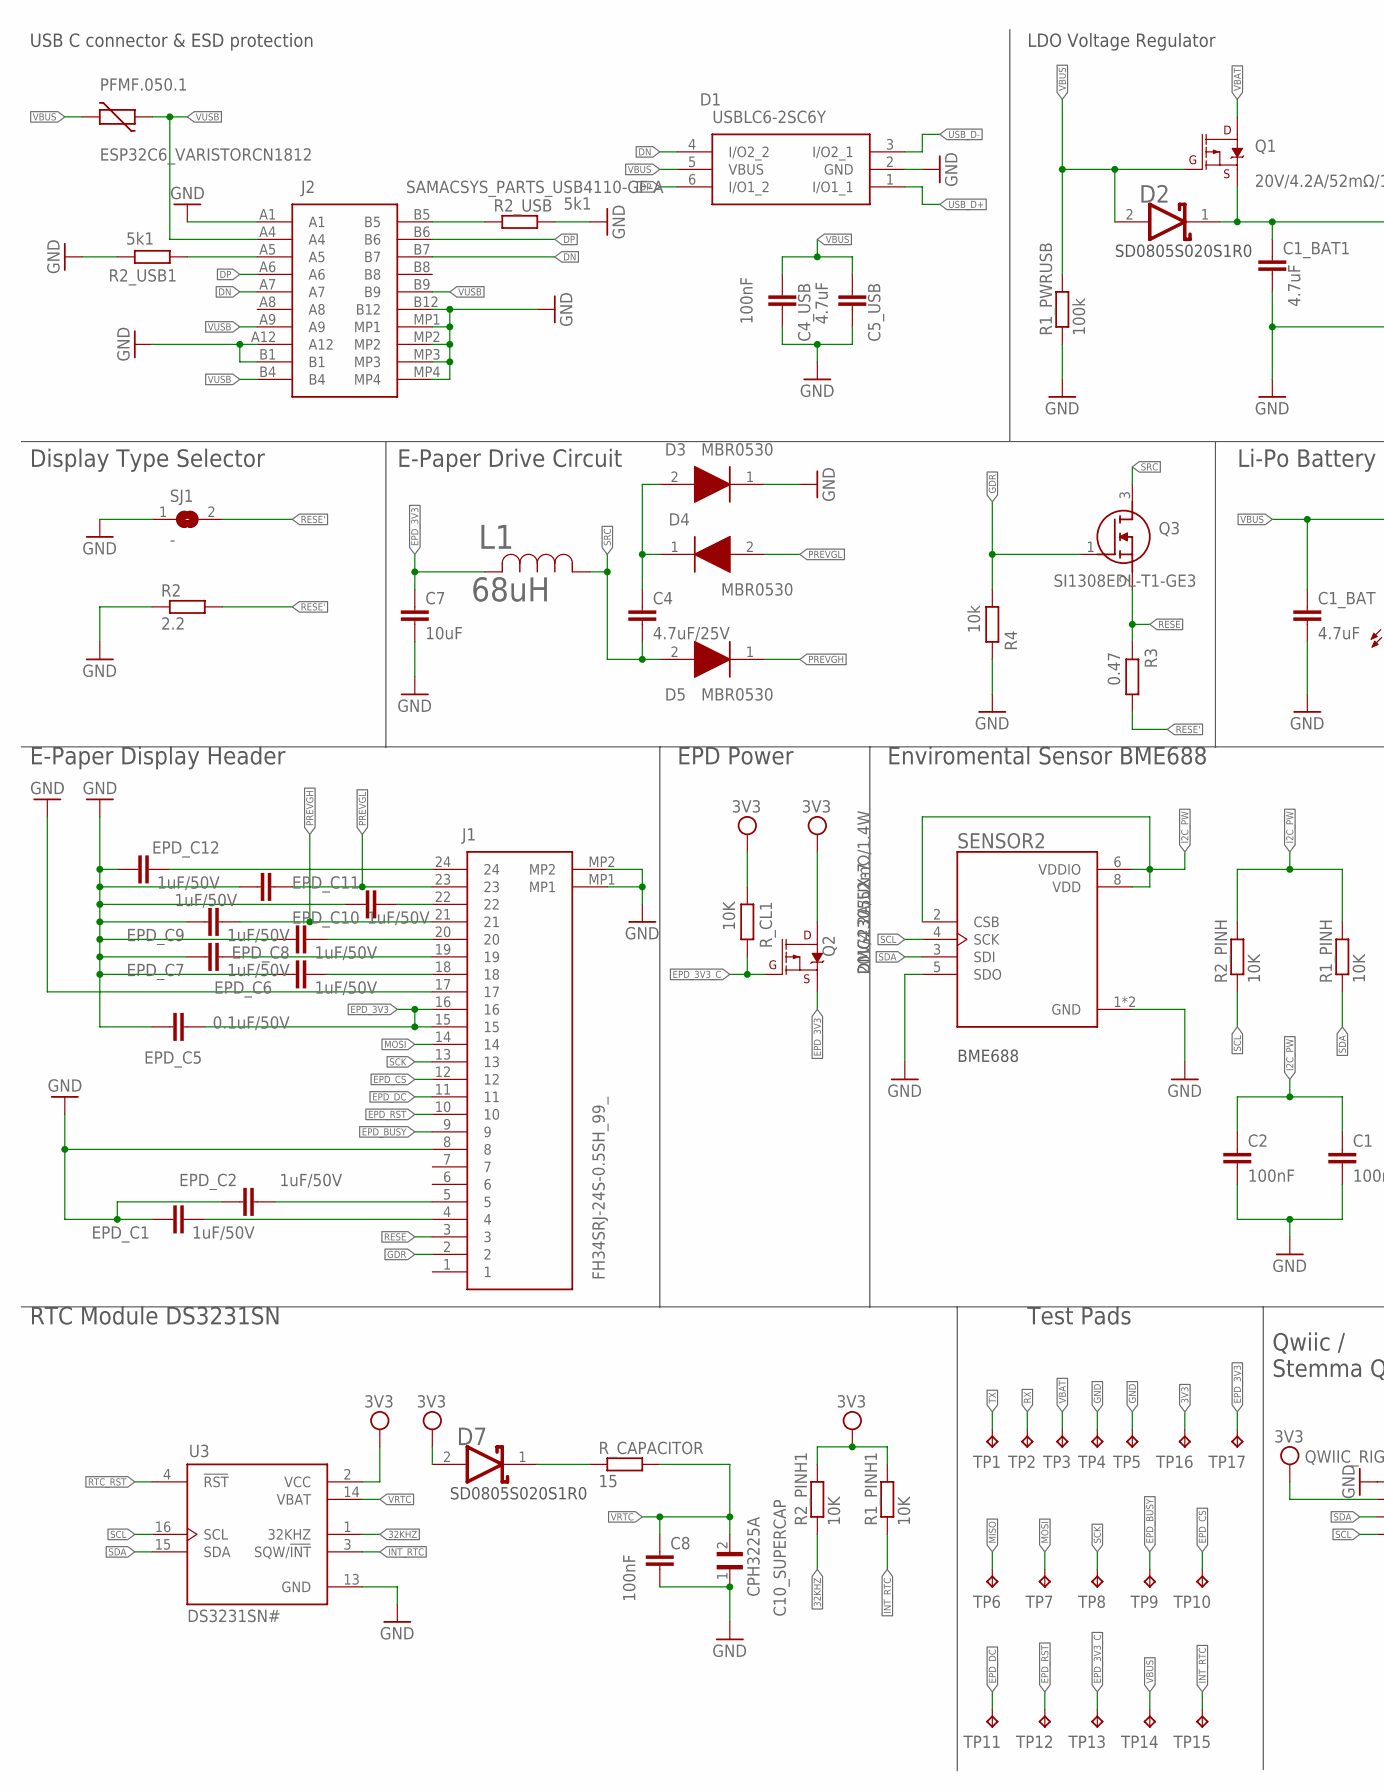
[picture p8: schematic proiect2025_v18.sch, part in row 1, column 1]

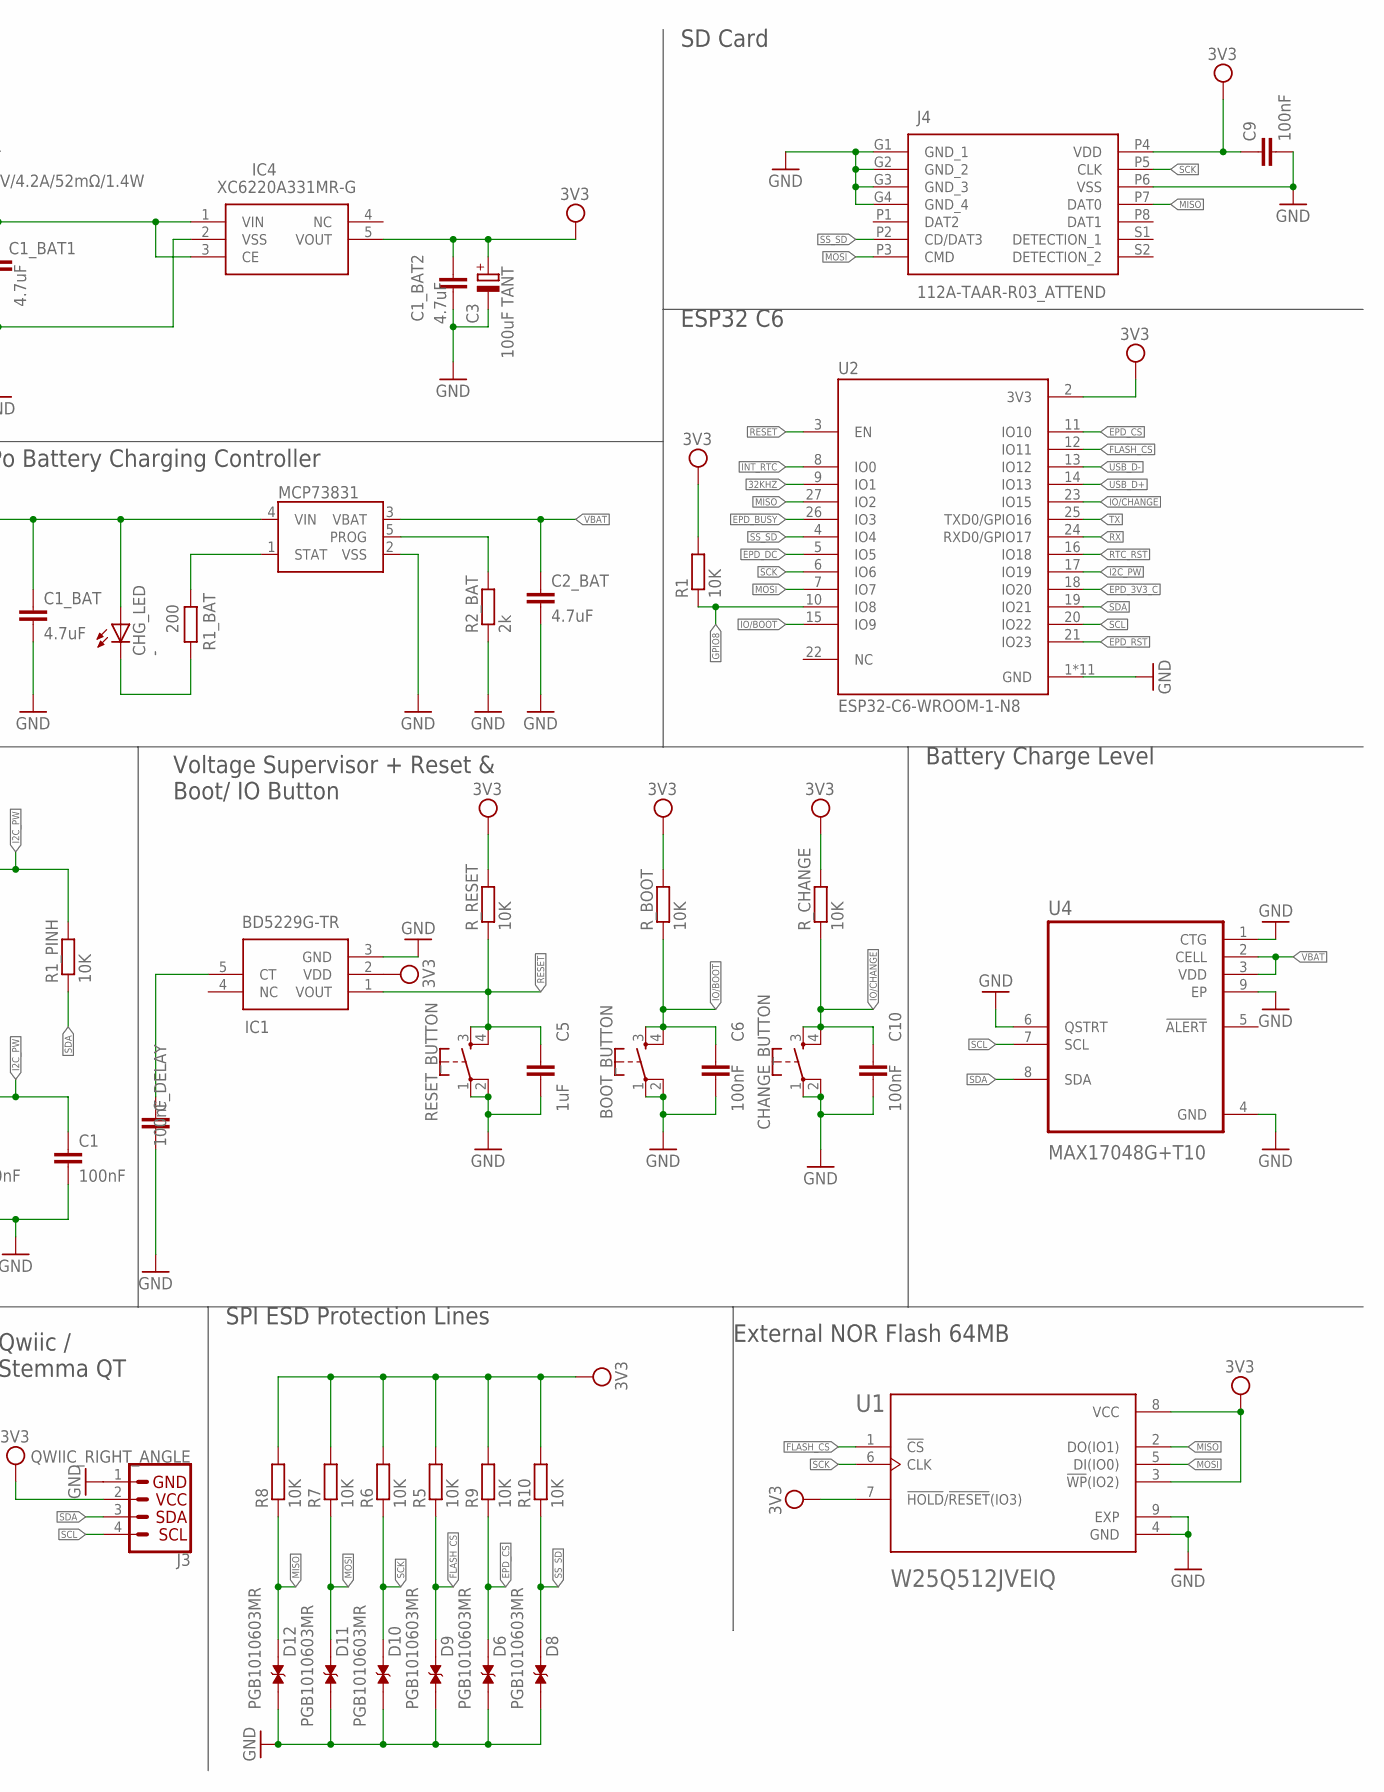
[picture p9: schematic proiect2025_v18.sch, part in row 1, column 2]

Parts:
BOOT_BUTTON: BUTTON_CUSYOMV1; MYBUTTON
C1, C2, C4_USB, C6, C8, C9, C10: 100nF; EAGLE-LTSPICE_C0402
C1_BAT, C1_BAT1, C1_BAT2, C2_BAT, C5_USB: 4.7uF; EAGLE-LTSPICE_C0402
C3: 100uF TANT; RCL_CT3528
C4: 4.7uF/25V; EAGLE-LTSPICE_C0402
C5: 1uF; EAGLE-LTSPICE_C0402
C7: 10uF; EAGLE-LTSPICE_C0402
C10_SUPERCAP: CPH3225A; CAPCP3225X100N
CHANGE_BUTTON: BUTTON_CUSYOMV1; MYBUTTON
CHG_LED: -; ADAFRUIT_CHIP-LED0603
C_DELAY: 100nF; EAGLE-LTSPICE_C0402
D1: USBLC6-2SC6Y; SOT95P280X145-6N
D2, D7: ESP32_WROVER_AVX---SD0805S020S1R0_AVX_SD0805S020S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; ESP32_WROVER_AVX---SD0805S020S1R0_AVX_SD0805S020S1R0_0
D3, D4, D5: MBR0530; SOD3716X135N
D6, D8, D9, D10, D11, D12: PGB1010603MR; DIOC1608X36N
EPD_C1, EPD_C2, EPD_C6, EPD_C7, EPD_C8, EPD_C9, EPD_C10, EPD_C11, EPD_C12: 1uF/50V; EAGLE-LTSPICE_C0402
EPD_C5: 0.1uF/50V; EAGLE-LTSPICE_C0402
IC1: BD5229G-TR; SOT95P280X125-5N
IC4: XC6220A331MR-G; SOT95P280X120-5N
J1: FH34SRJ-24S-0.5SH_99_; FH34SRJ24S05SH99
J2: SAMACSYS_PARTS_USB4110-GF-A; SAMACSYS_PARTS_USB4110GFA
J3: QWIIC_RIGHT_ANGLE; JST04_1MM_RA
J4: 112A-TAAR-R03_ATTEND; 112ATAARR03ATTEND
L1: 68uH; IND_4828-WE-TPC_WRE
MCP73831: ESP32_WROVER_SPARKFUN-IC-POWER_MCP73831; ESP32_WROVER_SPARKFUN-IC-POWER_SOT23-5
PFMF.050.1: ESP32C6_VARISTORCN1812; ESP32C6_VARISTOR_CT/CN1812
Q1, Q2: 20V/4.2A/52mΩ/1.4W; ESP32_WROVER_SPARKFUN-DISCRETESEMI_SOT23-3
Q3: SI1308EDL-T1-GE3; SOT65P210X110-3N
R1, R1_PINH, R1_PINH1, R2_PINH, R2_PINH1, R5, R6, R7, R8, R9, R10: 10K; ESP32_WROVER_EAGLE-LTSPICE_R0402
R1_BAT: 200; ESP32_WROVER_EAGLE-LTSPICE_R0402
R1_PWRUSB: 100k; ESP32_WROVER_EAGLE-LTSPICE_R0402
R2: 2.2; ESP32_WROVER_EAGLE-LTSPICE_R0402
R2_BAT: 2k; ESP32_WROVER_EAGLE-LTSPICE_R0402
R2_USB, R2_USB1: 5k1; ESP32_WROVER_EAGLE-LTSPICE_R0402
R3: 0.47; ESP32_WROVER_EAGLE-LTSPICE_R0402
R4: 10k; ESP32_WROVER_EAGLE-LTSPICE_R0402
RESET_BUTTON: BUTTON_CUSYOMV1; MYBUTTON
R_BOOT: 10K; ESP32_WROVER_EAGLE-LTSPICE_R0402
R_CAPACITOR: 15; ESP32_WROVER_EAGLE-LTSPICE_R0402
R_CHANGE: 10K; ESP32_WROVER_EAGLE-LTSPICE_R0402
R_CL1: 10K; ESP32_WROVER_EAGLE-LTSPICE_R0402
R_RESET: 10K; ESP32_WROVER_EAGLE-LTSPICE_R0402
SENSOR2: ESP32_WROVER_BME680_BME680; ESP32_WROVER_BME680_PSON80P300X300X100-8N
SJ1: -; SJ
TP1, TP2, TP3, TP4, TP5, TP6, TP7, TP8, TP9, TP10, TP11, TP12, TP13, TP14, TP15, TP16, TP17: TPTP20R; TP20R
U1: W25Q512JVEIQ; SON127P600X800X80-9N
U2: ESP32-C6-WROOM-1-N8; XCVR_ESP32-C6-WROOM-1-N8
U3: DS3231SN#; SOIC127P1032X265-16N
U4: MAX17048G+T10; SON50P200X200X80-9N

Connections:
3V3: C1_BAT2.1, C3.+, C9.1, D7.2 (ANODE), IC1.2 (VDD), IC4.5 (VOUT), J3.2, J4.P4 (VDD), Q2.3 (D), R1.2, R1_PINH1.2, R2_PINH1.2, R5.2, R6.2, R7.2, R8.2, R9.2, R10.2, R_BOOT.2, R_CHANGE.2, R_CL1.2, R_RESET.2, TP16.TP, U1.3 (!WP!(IO2)), U1.7 (!HOLD!/!RESET!(IO3)), U1.8 (VCC), U2.2 (3V3), U3.2 (VCC)
32KHZ: R2_PINH1.1, U2.9 (IO1), U3.1 (32KHZ)
DN: D1.4 (I/O2_2), J2.A7, J2.B7
DP: D1.6 (I/O1_2), J2.A6, J2.B6
EPD_3V3: C7.1, EPD_C5.2, J1.15, J1.16, L1.2, Q2.2 (S), TP17.TP
EPD_3V3_C: Q2.1 (G), R_CL1.1, TP13.TP, U2.18 (IO20)
EPD_BUSY: J1.9, TP9.TP, U2.26 (IO3)
EPD_CS: D6.2, J1.12, R9.1, TP10.TP, U2.11 (IO10)
EPD_DC: J1.11, TP11.TP, U2.5 (IO5)
EPD_RST: J1.10, TP12.TP, U2.21 (IO23)
FLASH_CS: D9.2, R5.1, U1.1 (!CS), U2.12 (IO11)
GDR: J1.2, Q3.1 (G), R4.2
GND: BOOT_BUTTON.1, BOOT_BUTTON.2, C1.2, C1_BAT.2, C1_BAT1.2, C1_BAT2.2, C2.2, C2_BAT.2, C3.-, C4_USB.2, C5.2, C5_USB.2, C6.2, C7.2, C8.2, C9.2, C10.2, C10_SUPERCAP.1, CHANGE_BUTTON.1, CHANGE_BUTTON.2, C_DELAY.2, D1.2 (GND), D3.1 (K), D6.1, D8.1, D9.1, D10.1, D11.1, D12.1, EPD_C1.1, EPD_C2.1, EPD_C5.1, EPD_C6.1, EPD_C7.1, EPD_C8.1, EPD_C9.1, EPD_C10.1, EPD_C11.1, EPD_C12.1, IC1.3 (GND), IC4.2 (VSS), J1.8, J1.17, J1.MP1, J1.MP2, J2.A1, J2.A12, J2.B1, J2.B12, J2.MP1, J2.MP2, J2.MP3, J2.MP4, J3.1, J4.G1 (GND_1), J4.G2 (GND_2), J4.G3 (GND_3), J4.G4 (GND_4), J4.P6 (VSS), MCP73831.2 (VSS), R1_PWRUSB.1, R2.1, R2_BAT.1, R2_USB.2, R2_USB1.1, R4.1, RESET_BUTTON.1, RESET_BUTTON.2, SENSOR2.1 (GND), SENSOR2.5 (SDO), SENSOR2.7 (GND), SJ1.1, TP4.TP, TP5.TP, U1.4 (GND), U1.9 (EXP), U2.1 (GND), U2.28 (GND), U2.29_1 (GND), U2.29_2 (GND), U2.29_3 (GND), U2.29_4 (GND), U2.29_5 (GND), U2.29_6 (GND), U2.29_7 (GND), U2.29_8 (GND), U2.29_9 (GND), U3.13 (GND), U4.1 (CTG), U4.4 (GND), U4.6 (QSTRT), U4.9 (EP)
GPIO8: R1.1, U2.10 (IO8)
I2C_PW: C1.1, C2.1, R1_PINH.2, R2_PINH.2, SENSOR2.2 (CSB), SENSOR2.6 (VDDIO), SENSOR2.8 (VDD), U2.17 (IO19)
INT_RTC: R1_PINH1.1, TP15.TP, U2.8 (IO0), U3.3 (SQW/!INT)
IO/BOOT: BOOT_BUTTON.3, BOOT_BUTTON.4, C6.1, R_BOOT.1, U2.15 (IO9)
IO/CHANGE: C10.1, CHANGE_BUTTON.3, CHANGE_BUTTON.4, R_CHANGE.1, U2.23 (IO15)
MISO: D12.2, J4.P7 (DAT0), R8.1, TP6.TP, U1.2 (DO(IO1)), U2.27 (IO2)
MOSI: D11.2, J1.14, J4.P3 (CMD), R7.1, TP7.TP, U1.5 (DI(IO0)), U2.7 (IO7)
unnamed: J2.A5, R2_USB1.2
unnamed: EPD_C12.2, J1.24
unnamed: C1_BAT1.1, D2.1 (CATHODE), IC4.1 (VIN), IC4.3 (CE), Q1.2 (S)
unnamed: C4.1, D3.2 (A), D4.1 (K)
unnamed: CHG_LED.C, R1_BAT.1
unnamed: MCP73831.1 (STAT), R1_BAT.2
unnamed: J2.B5, R2_USB.1
unnamed: MCP73831.5 (PROG), R2_BAT.2
unnamed: C_DELAY.1, IC1.5 (CT)
unnamed: EPD_C10.2, J1.22
unnamed: EPD_C8.2, J1.20
unnamed: EPD_C7.2, J1.19
unnamed: EPD_C6.2, J1.18
unnamed: D7.1 (CATHODE), R_CAPACITOR.1
unnamed: EPD_C2.2, J1.5
unnamed: EPD_C1.2, J1.4
PREVGH: D5.1 (K), EPD_C9.2, J1.21
PREVGL: D4.2 (A), EPD_C11.2, J1.23
RESE: J1.3, Q3.2 (S), R3.2
RESE': R2.2, R3.1, SJ1.2
RESET: C5.1, IC1.1 (VOUT), RESET_BUTTON.3, RESET_BUTTON.4, R_RESET.1, U2.3 (EN)
RTC_RST: U2.16 (IO18), U3.4 (!RST)
RX: TP2.TP, U2.24 (RXD0/GPIO17)
SCK: D10.2, J1.13, J4.P5 (CLK), R6.1, TP8.TP, U1.6 (CLK), U2.6 (IO6)
SCL: J3.4, R2_PINH.1, SENSOR2.4 (SCK), U2.20 (IO22), U3.16 (SCL), U4.7 (SCL)
SDA: J3.3, R1_PINH.1, SENSOR2.3 (SDI), U2.19 (IO21), U3.15 (SDA), U4.8 (SDA)
SRC: C4.2, D5.2 (A), L1.1, Q3.3 (D)
SS_SD: D8.2, J4.P2 (CD/DAT3), R10.1, U2.4 (IO4)
TX: TP1.TP, U2.25 (TXD0/GPIO16)
USB_D+: D1.1 (I/O1_1), U2.14 (IO13)
USB_D-: D1.3 (I/O2_1), U2.13 (IO12)
VBAT: C2_BAT.1, MCP73831.3 (VBAT), Q1.3 (D), TP3.TP, U4.2 (CELL), U4.3 (VDD)
VBUS: C1_BAT.1, C4_USB.1, C5_USB.1, CHG_LED.A, D1.5 (VBUS), D2.2 (ANODE), MCP73831.4 (VIN), PFMF.050.1.2, Q1.1 (G), R1_PWRUSB.2, TP14.TP
VRTC: C8.1, C10_SUPERCAP.2, R_CAPACITOR.2, U3.14 (VBAT)
VUSB: J2.A4, J2.A9, J2.B4, J2.B9, PFMF.050.1.1

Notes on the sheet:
USB C connector & ESD protection
LDO Voltage Regulator
SD Card
Display Type Selector
E-Paper Drive Circuit
Li-Po Battery Charging Controller
ESP32 C6
E-Paper Display Header
EPD Power
Enviromental Sensor BME688
Voltage Supervisor + Reset & Boot/ IO Button
Battery Charge Level
RTC Module DS3231SN
Test Pads
Qwiic / Stemma QT
SPI ESD Protection Lines
External NOR Flash 64MB
SD0805S020S1R0
DMG2305UX-7
BME688

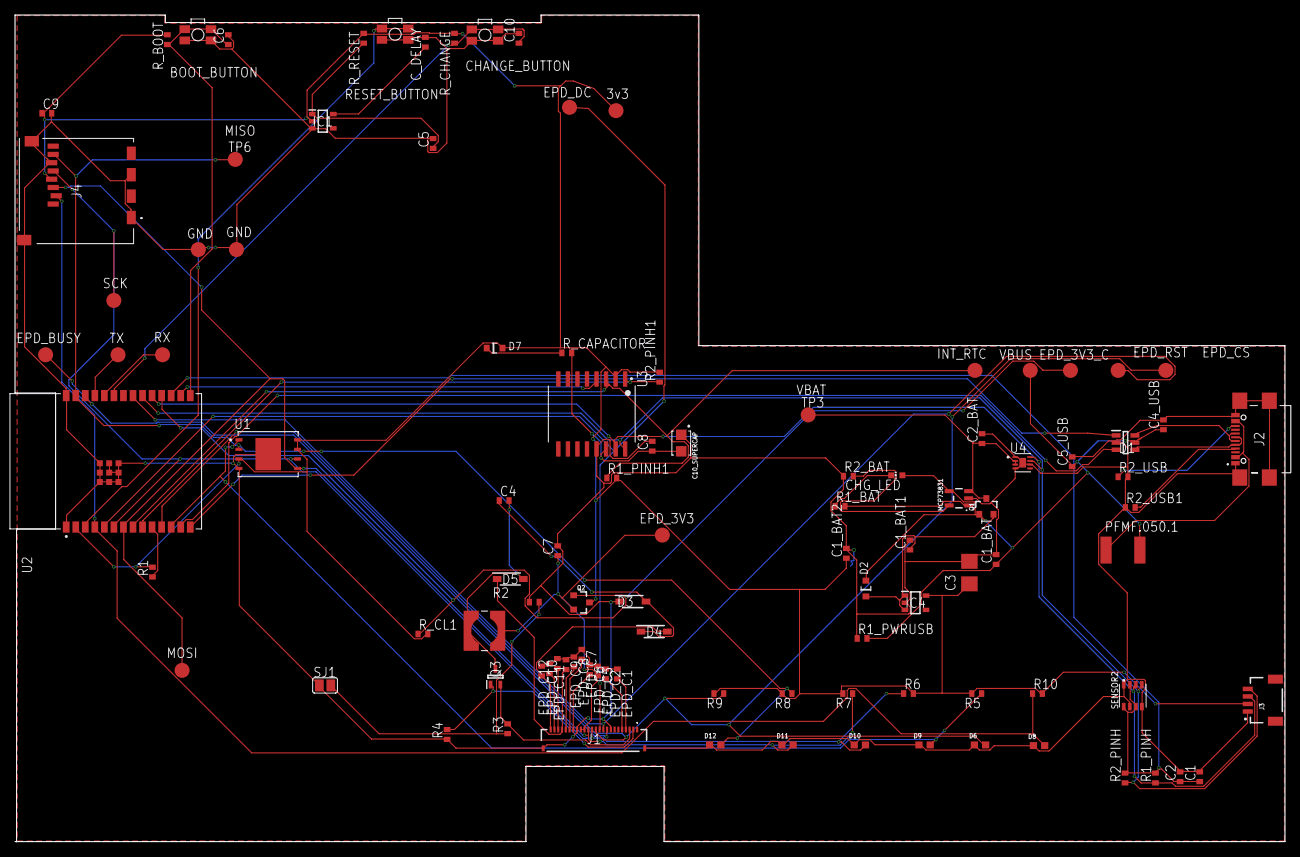
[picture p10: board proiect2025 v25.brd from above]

Board: 2 copper layers, 169.0 x 110.0 mm, 103 parts (0 on the bottom side), 55 nets.

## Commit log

2025-04-06 Upload Project
    [BOM_proiect2025 v19.csv, PnP_proiect2025 v19_back.csv, PnP_proiect2025 v19_front.csv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]
2025-04-11 Fix after review
    [proiect2025 v16_sch.sch, proiect2025 v21_pcb.brd, proiect2025 v25.brd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]
2025-04-12 Solved issues
    [BOM_proiect2025 v19.csv]

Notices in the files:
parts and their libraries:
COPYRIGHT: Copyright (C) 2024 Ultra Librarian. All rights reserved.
